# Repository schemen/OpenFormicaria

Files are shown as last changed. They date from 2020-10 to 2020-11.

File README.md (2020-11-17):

# OpenFormicaria

A Open Source modular ant formicarium and home with simple space saving connectors.

**Documentation:** [https://of.schemen.me](https://of.schemen.me)

**How to Contribute:** [https://of.schemen.me/contrib/](https://of.schemen.me/contrib/)

## Features overview

OpenFormicaria is a set of parts that interconnect expand upon another. Any part is compatible with any other part ranging from the small Portal where you can found your colony after the test tube up to interconnecting many formicaria.

All modules are based on a 35mmx35mm base grid for ability to interconnect all of them (At least connector facing parts). 4xGateway is 35x35mm, 6xGateway is 35x70mm. All of the modules are 20mm high.

* A variety of connectors to connect modules, formicaria, tubes etc.
* Connectors can be exchanged safely while the part is in use to prevent ant escapees.
* Different sizes of formicaria for different colony sizes
* Different formicaria insert styles for different ant species
* Easy way to create your own custom insert!
* Portal module with feeding access for a first small outworld to explore and expand
* 4x or 6x Gateway modules to expand the farm

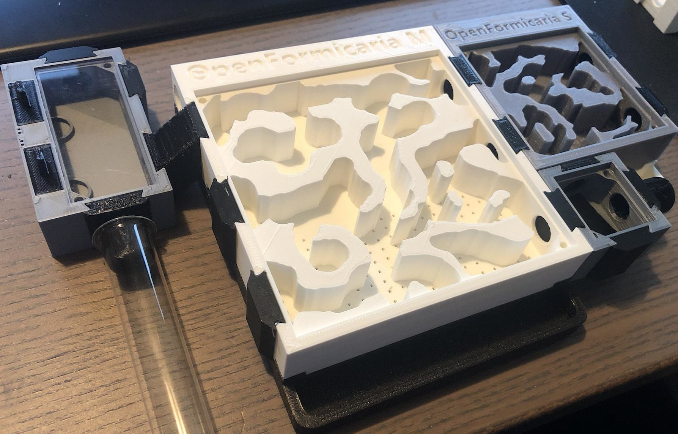
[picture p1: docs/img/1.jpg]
Example Farm


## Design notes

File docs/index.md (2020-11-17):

# Welcome to OpenFormicaria

This is a open source modular ant formicarium and home with simple space saving connectors.

## Features overview

OpenFormicaria is a set of parts that interconnect and expand upon another. Any part is compatible with any other part ranging from the small Portal where you can establish your colony after the test tube up to interconnecting many formicaria.

All modules are based on a 35mmx35mm base grid for ability to interconnect all of them (at least connector facing parts). 4xGateway is 35x35mm, 6xGateway is 35x70mm. All of the modules are 20mm high.

* A variety of connectors to connect modules, formicaria, tubes etc
* Connectors can be exchanged safely while the part is in use to prevent ant escapees
* Different sizes of formicaria for different colony sizes
* Different formicaria insert styles for different ant species
* Easy way to create your own custom insert!
* Portal module with feeding access for a first, small outworld to explore and expand
* 4x or 6x Gateway modules to expand the farm

Example Farm

## Reading On

Do you want to go ahead and print your own ant nest or a starting base?
Continue reading with [Getting Started](getting_started.md).

If you want to contribute, add more parts and modules, want to improve existing ones or simply want to help out, please have a look at [How to contribute](contrib.md)

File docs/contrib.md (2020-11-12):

# How to expand OpenFormicaria
There are several processes and standards within this project, so let's have a look at them.

Generally, I **recommend** using a existing CAD instance as reference and work with CV2 connector style.

You can find the repository here: [Github](https://github.com/schemen/OpenFormicaria)

Fork it and add your changes. 

## How to PR/MR on Github
When you have a creation you want to have added, make sure it is in the correct folder (STL exports, CAD files etc.).
Add the documentation of your part in to `docs` folder as well.

Please create PRs into the **devel** branch!

## Base structural blocks for any modules
A base block has the size of **35mmx35mmx20mm**. The 4xGateway has essentially those measurments. This square is essentially the base block size for connenctor facing faces.

You can see this with the the 6xGateway. On a side, they have two connector placements, this side has to be 70mm wide to fit both of them. A face that does not intend to have connectors, you are free to move out of this size. The example here would be the Portal. The face with the feeder holes is a bit outside of this box.

### Some other specs to modules
* The glass cut out is 3mm deep
* The m3 screw holes have a radius of 1.4mm
* The ant "cutout" is recommended to be around 15mm deep. This leads to have a 2mm floor with 20mm total height. 
* To hold the glass I've used a 1mm wide ledge sofar

## Connector
Please have a look at the folder `Measurements` with all the detailing measurements on how the connector looks like. 

A connector is set up with the following parts:

* Female Connector is on all Modules. Be aware in the difference of CV1 and CV2. Have a look at the image `Connector Cut Measurements`.
  * The hole cut through has a radius of **5mm** and is centered.
  * CV2 Female has a Hill that is in the center. Check `ConnectorV2_Hill` for it's specs
* Male connectors are standalone and are used in between to connect all modules. The CV2 version as a grove and a rail so that the Hill can slide and lock. 
  * Check out the images `ConnectorV2_Rail` and "`ConnectorV2_Groove` for the specs

## Formicaria
The formicaria are created in two steps:

**1)** A template is created and maintained for each size. This template is empty and does not have any ant digging site, just free space. This gets exported as STL.

**2)** In Photoshop or any editor of your preference a black/white plan of the ant pathways is drawn. This then get imported in 3D Builder and placed into the template, combining the two.

This approach allows to create many different inserts for the formicaria for different ant species. You can of course further customize the templates if you wish.

Have a look at `Formicaria/Inserts/` to find PSD templates and already generated ant styles.

## Helping in other ways

If you like the design and all the work that already went in, you could consider sponsoring a tea/coffe at [Buymeacoffee](https://www.buymeacoffee.com/schemen) as a motivator!

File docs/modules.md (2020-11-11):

# OpenFormicaria - Modules

## Available modules
A list of Modules that are available!
Note all modules are available in CV1(Legacy) and CV2 trim.

## Print recommendations
All modules can be printed with:

* 0.2mm layer height
* 15% infill
* PLA or any other hard material
* The feeder lids should be printed in TPU to press in properly.

Use a color that is relatively contrastring to your ants so you can see them.

## Portal
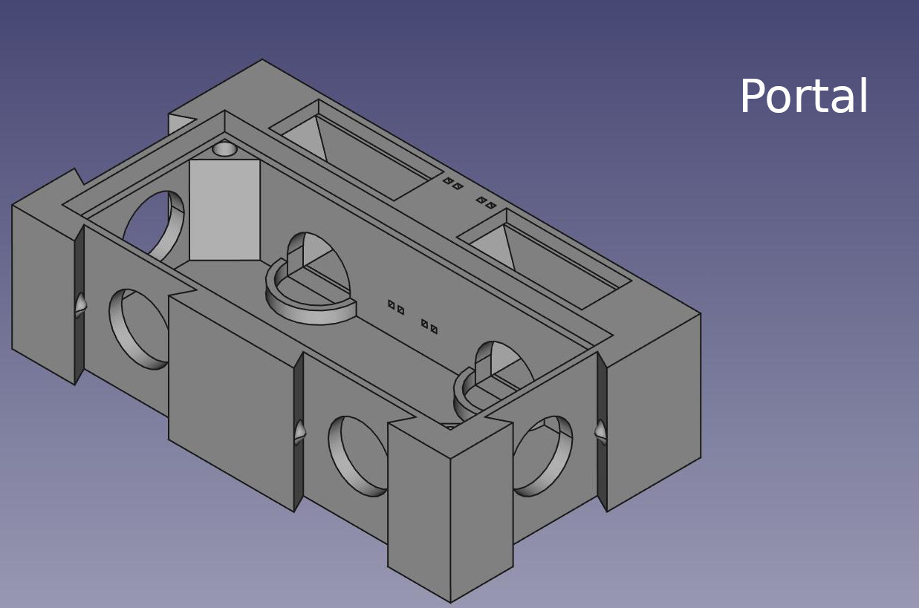
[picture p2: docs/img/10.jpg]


A module used for founding colonies. Connect your test tube with the queen and brood and the initial few workers here.
This module serves as the first small outworld!

Don't forget to print the cover and feeder lids. The feeder lids should be printed in TPU to press in properly.

### Features
* Size of 70mm x 40mm x 20mm
* Attach up to 4 other attachments
* Two feeding holes
* Air vents
* Lid to cover the ants if needed
* Either press fit or screw in plexiglass

### Plexiglass sizing
The glass cutout is 26mm x 62mm. If you want, you can use a small drill bit that fits M3 screws.

## 4xGateway
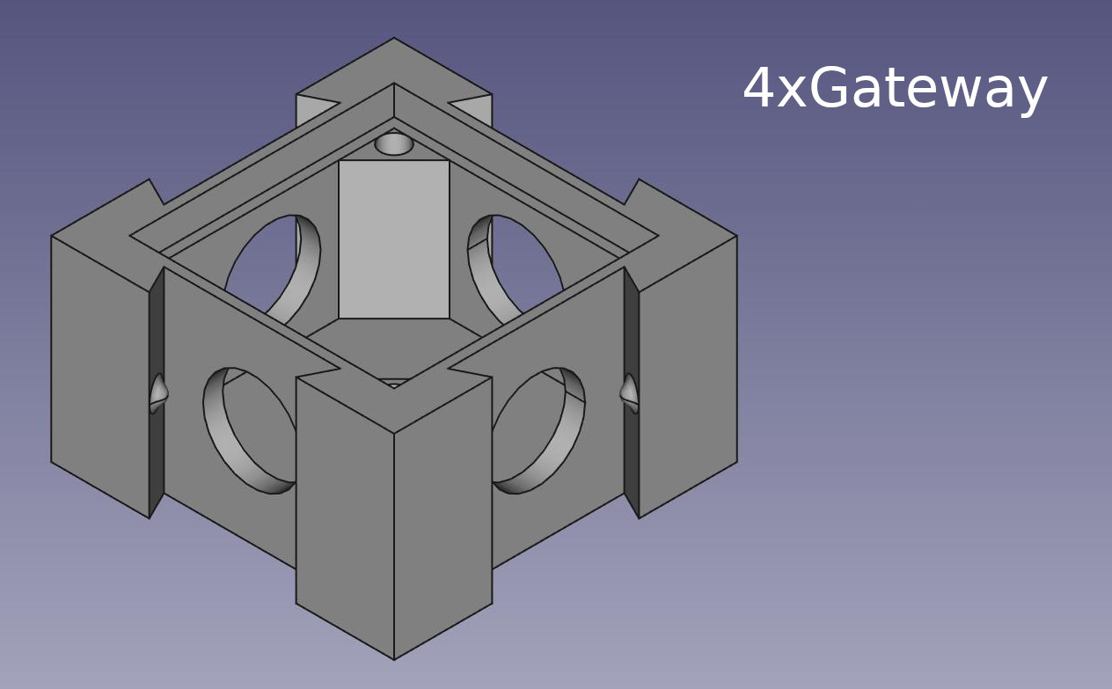
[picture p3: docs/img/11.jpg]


### Features
* Size of 35mm x 35mm x 20mm
* Attach up to 4 other attachements
* Plexiglass for your viewing pleasure

### Plexiglass sizing
The glass cutout is 27mm x 27mm. If you want, you can use a small drill bit that fits M3 screws.

## 6xGateway
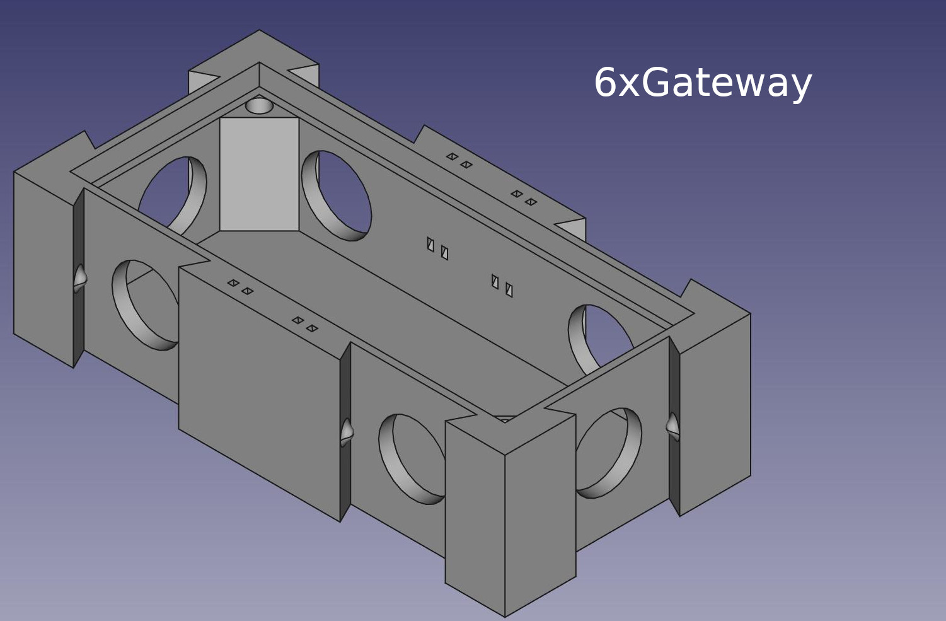
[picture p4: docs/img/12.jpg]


### Features
* Size of 70mm x 35mm x 20mm
* Attach up to 6 other attachements or things that can have two or more at the same time!
* More space
* Air Vents
* Plexiglass for your viewing pleasure

### Plexiglass sizing
The glass cutout is 62mm x 27mm. If you want, you can use a small drill bit that fits M3 screws.

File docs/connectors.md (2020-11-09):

# OpenFormicaria - Connectors

The images will be for CV2 mostly, though in most cases the information is valid for both version, if not explicitly said so.

## Print recommendation
### CV2 (recommended)
You have to use TPU or a similar flexible material.

* 0.2mm layer height is fine
* 15% infill
* Tube connectors require support, everything else can be printed without

### CV1
PLA is fine for most connectors, though the tube connector will not work properly with PLA.

* 0.2mm layer height is fine
* 15% infill
* Tube connectors require support as well as has to be printed with TPU, everything else can be printed without supports

## Main Connector 
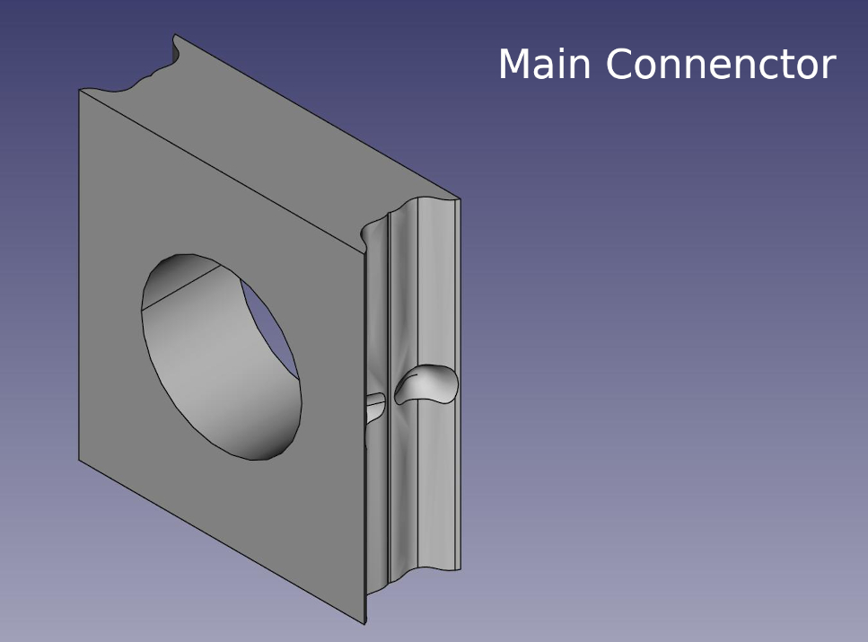
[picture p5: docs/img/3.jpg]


This connector connects two modules together, simple enough.

## Connector blocker
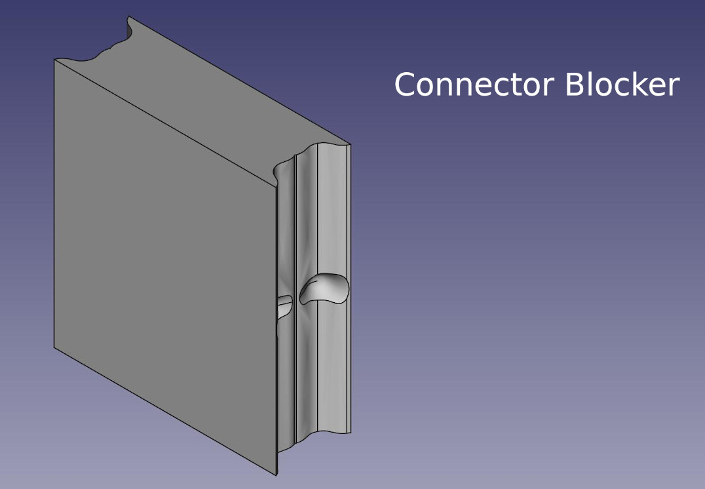
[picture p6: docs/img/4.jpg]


Same formfactor as the Main connector but it blocks the path.

## Tube Connectors for 10mm, 12mm and 14mm inner circumference
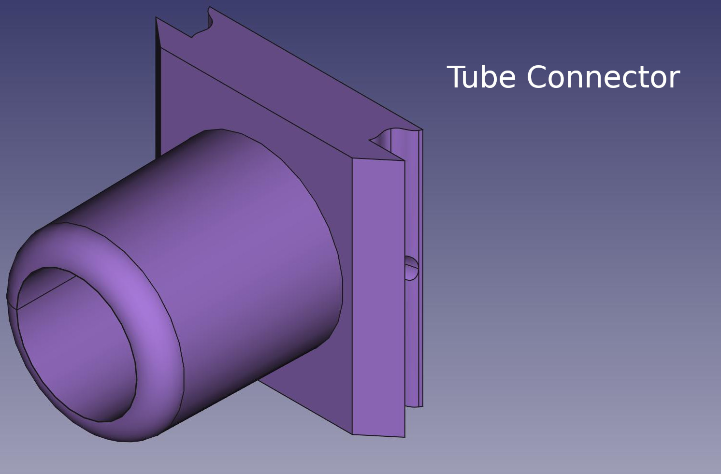
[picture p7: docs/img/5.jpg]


A variation of tube connectors. The test-/tubes go over the connector, not in.

**IMPORTANT**! Do not print this with PLA, use a flexible filament.

## Tube Connectors on an 90° angle for 10mm, 12mm and 14mm inner circumference
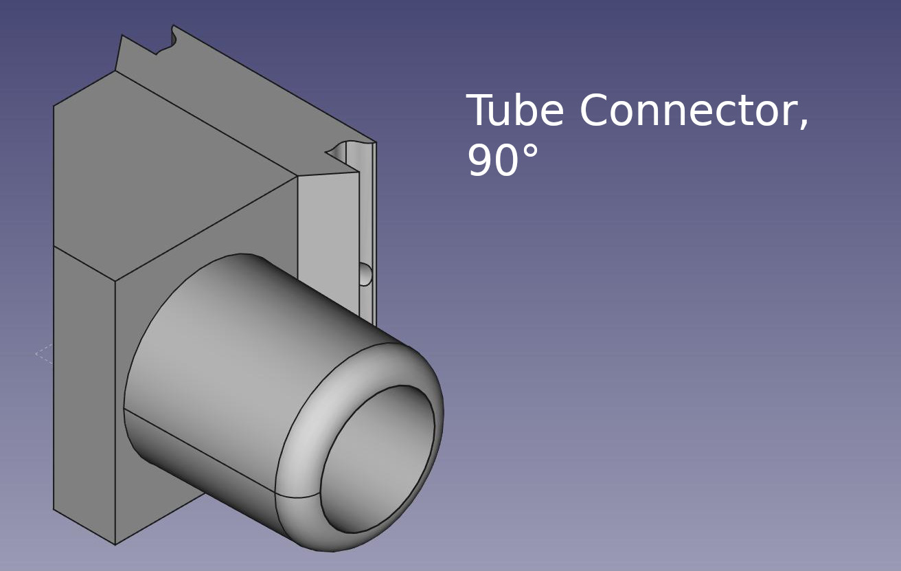
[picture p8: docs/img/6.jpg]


A variation of tube connectors. The test-/tubes go over the connector, not in.

IMPORTANT! Do not print this with PLA, use a flexible filament.

## Blocking Endpoint
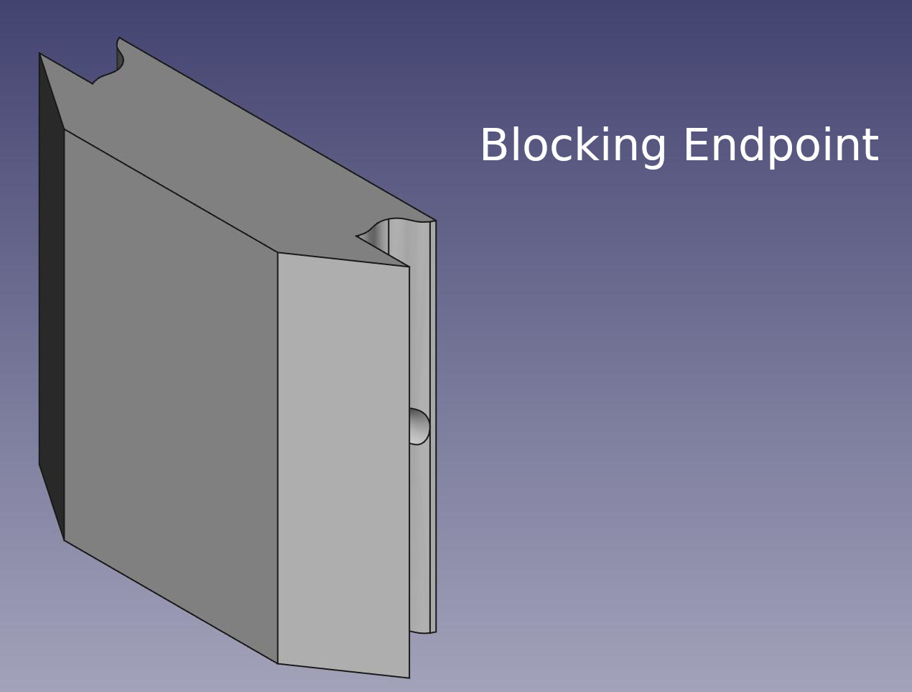
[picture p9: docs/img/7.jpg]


A bit nicer looking than a block connector but cannot be used to connect two modules

## Connector Raiser 
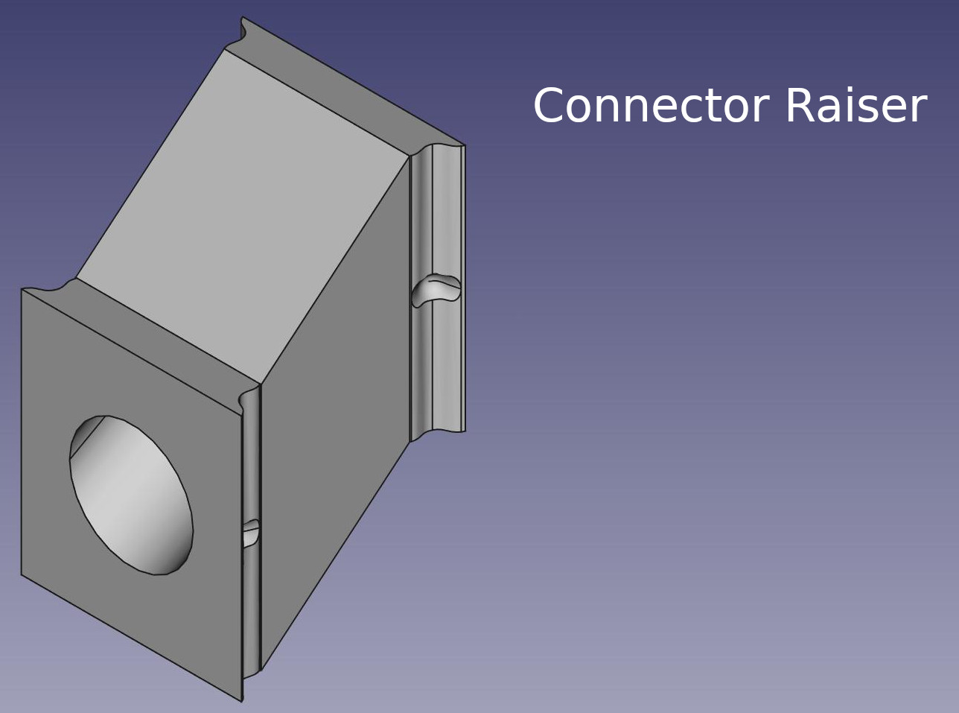
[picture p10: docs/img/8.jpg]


This connector allows you to connect a modules like a Portal to a formicarium which is higher above due to the basin. Now there is no more floating modules.

## Separator (CV2 only)
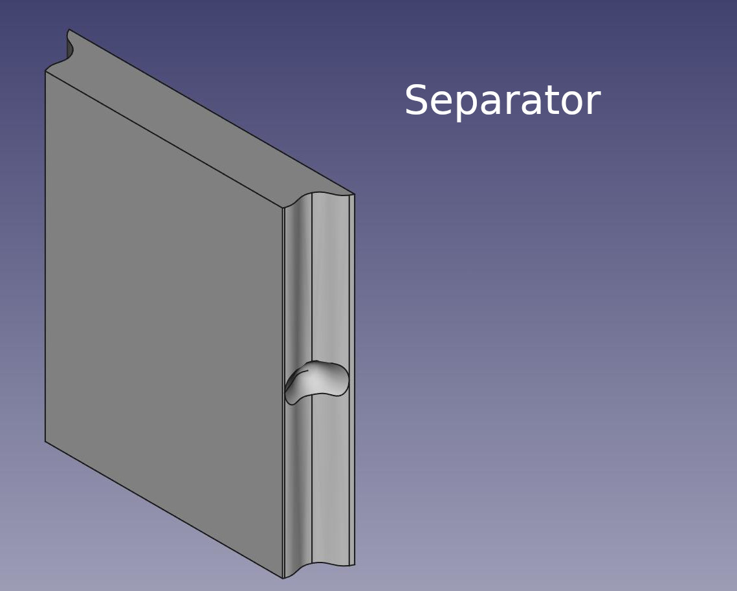
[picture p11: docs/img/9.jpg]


This "connector" allows you to separate two connected modules and block both entries. I recommend to print at least a pair of these for your setup.

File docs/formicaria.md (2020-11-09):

# OpenFormicaria - Formicaria

## General Features
* Modular - any type of insert can be made for specific ant requirements and preferences
* Water Basin Stack for hydration and humidity regulation
* Heat Cable insert
* Cover to give the ants a dark environment
* Plexiglass can be press fitted or via screws
* All Formicaria are available in CV1(Legacy) and CV2 trim

Don't forget to print the basin and lid for your nest!

## Formicaria Size S
Small size formicarium, 70mm x 80mm x 20mm.

### Template Size S
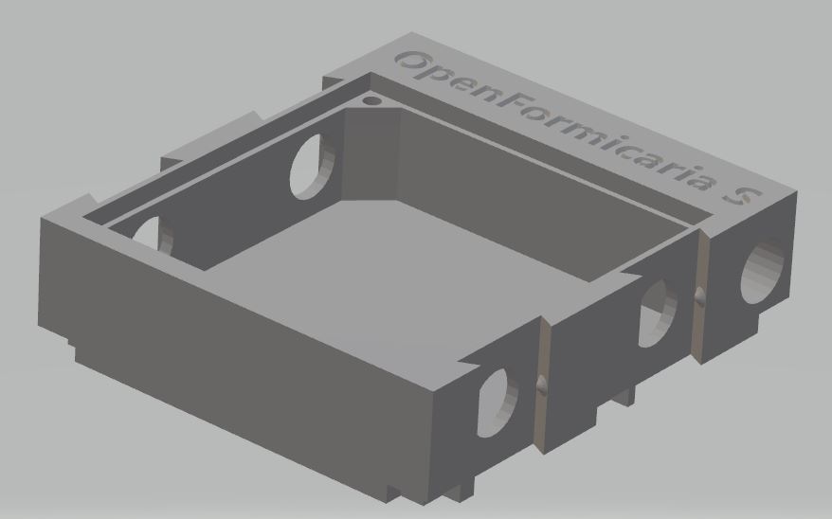
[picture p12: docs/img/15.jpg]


Do it yourself with Photoshop and Microsoft 3D Builder!

### Lasius S
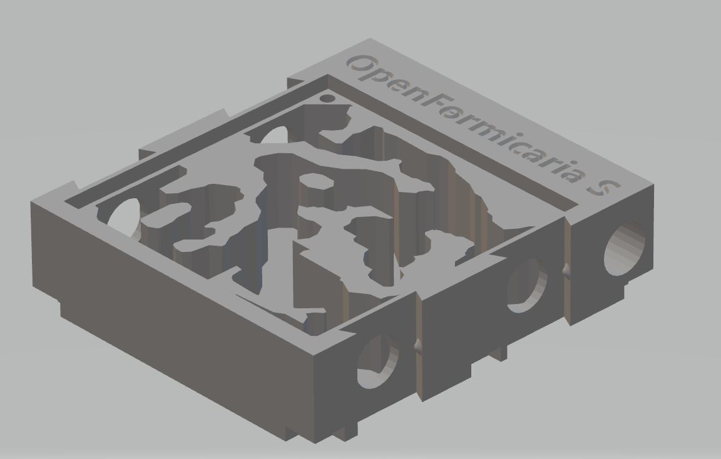
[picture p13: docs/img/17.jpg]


Lasius nest inspired insert

### Plexiglass sizing
The glass cutout is 62mm x 62mm. If you want, you can use a small drill bit that fits M3 screws.

## Formicaria Size M

Medium size formicarium, 105mm x 115mm x 20mm.

### Template Size M
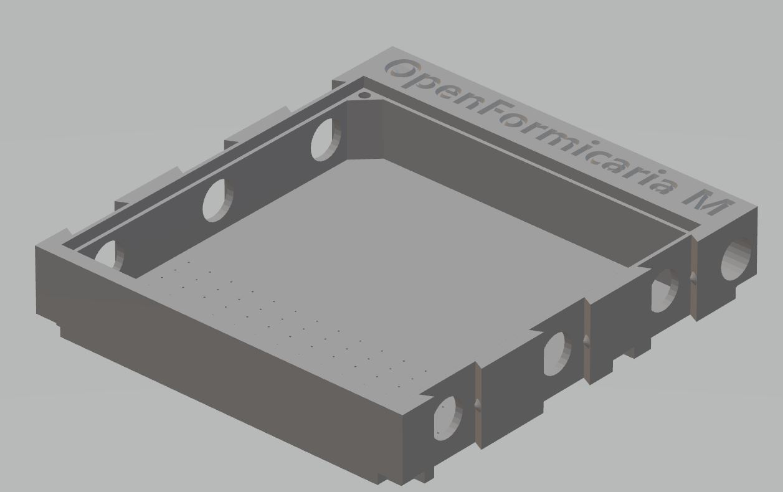
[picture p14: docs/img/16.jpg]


Do it yourself with Photoshop and Microsoft 3D Builder!

### Lasius M
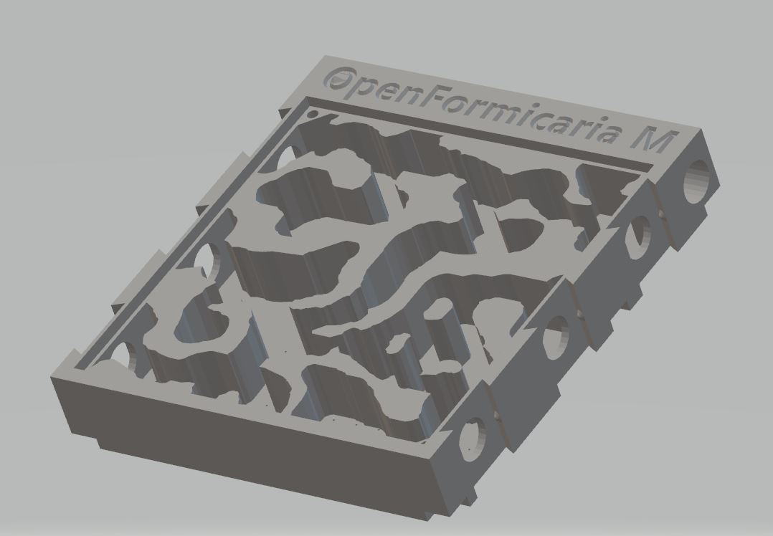
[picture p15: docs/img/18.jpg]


Lasius nest inspired insert

### Plexiglass sizing
The glass cutout is 97mm x 97mm. If you want, you can use a small drill bit that fits M3 screws.

## Other sizes
* Coming soon!

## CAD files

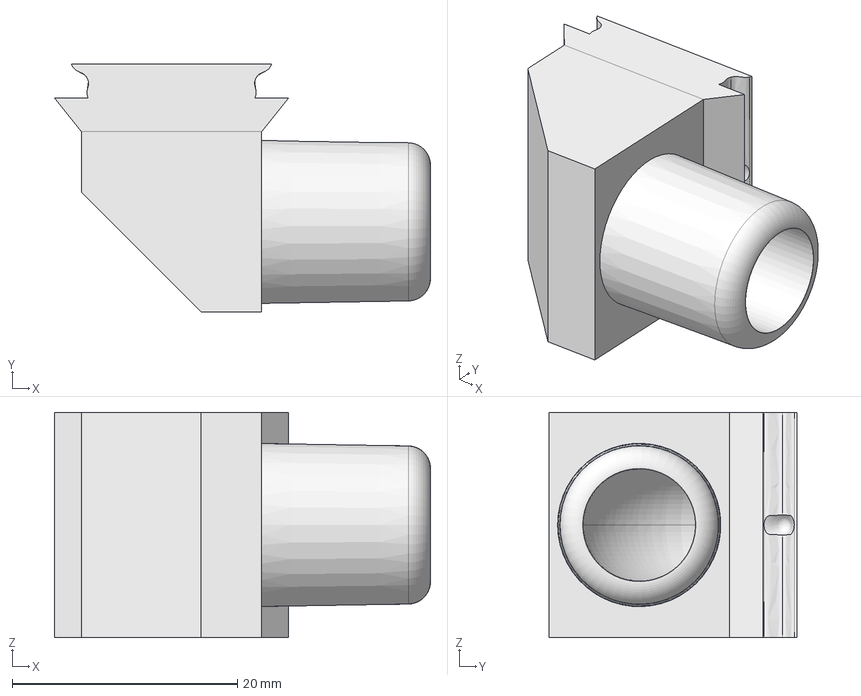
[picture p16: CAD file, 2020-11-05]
Connectors/CAD/Connector Version 2/V2_Connector_90deg_tube_14mm.FCStd
33.4 x 22.0 x 20.0 mm

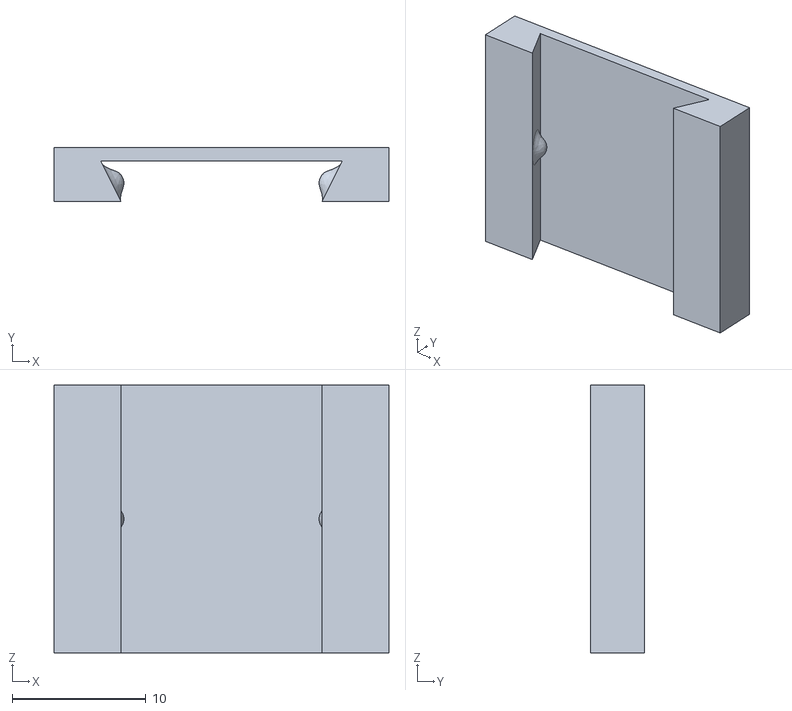
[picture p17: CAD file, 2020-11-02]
Connectors/STL/connectorv2.stl
25.0 x 4.00 x 20.0

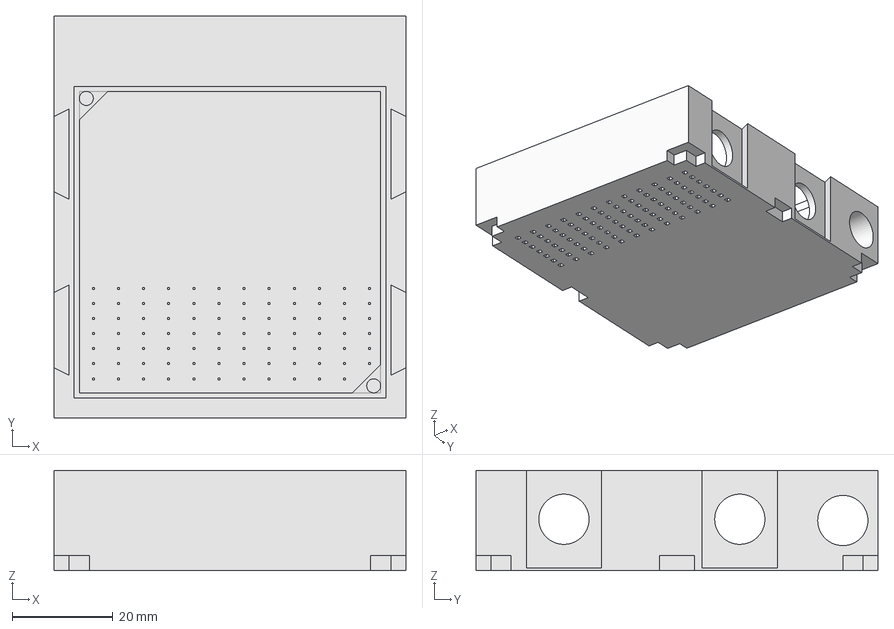
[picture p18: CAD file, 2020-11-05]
Formicaria/CAD/CV1/Formicarium_Template_S.FCStd
70.0 x 80.0 x 20.0 mm

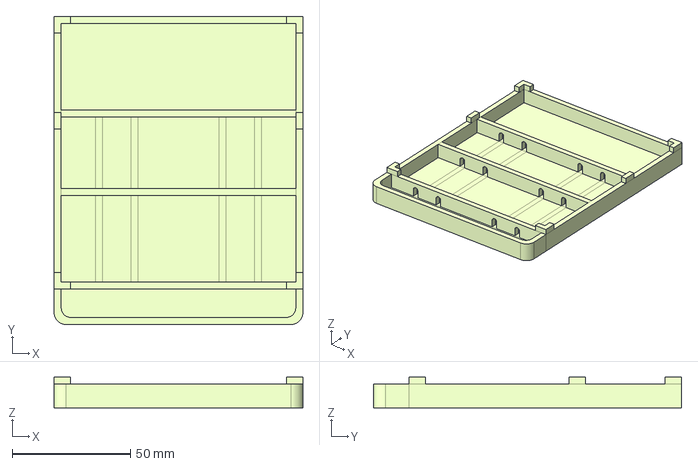
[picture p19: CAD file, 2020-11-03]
Formicaria/CAD/Formicarium_basin_M.FCStd
105.0 x 130.0 x 13.0 mm

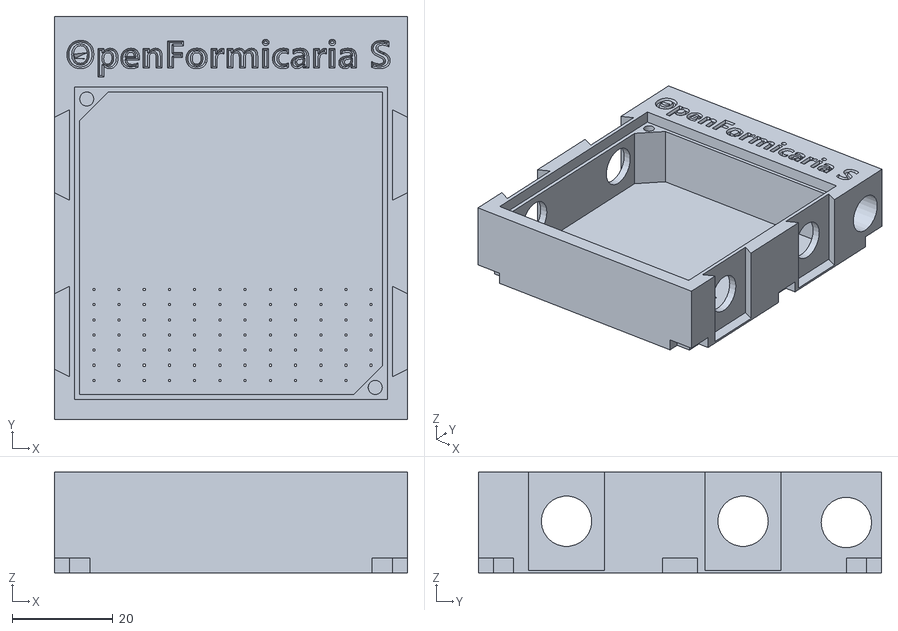
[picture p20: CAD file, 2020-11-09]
Formicaria/STL/CV1/OF_Formicarium_Template_S.stl
70.0 x 80.0 x 20.0

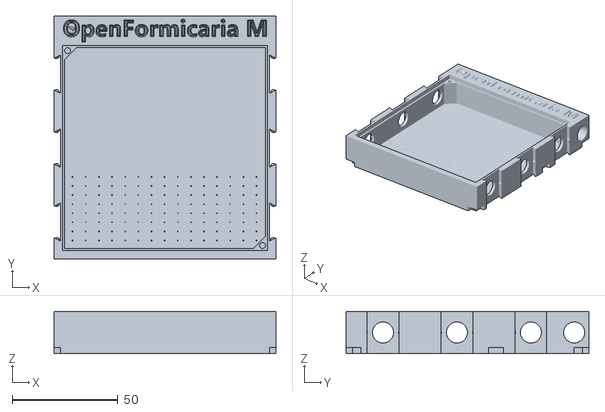
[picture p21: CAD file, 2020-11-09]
Formicaria/STL/CV2/CV2_OF_Formicarium_Template_M.stl
105.0 x 115.0 x 20.0

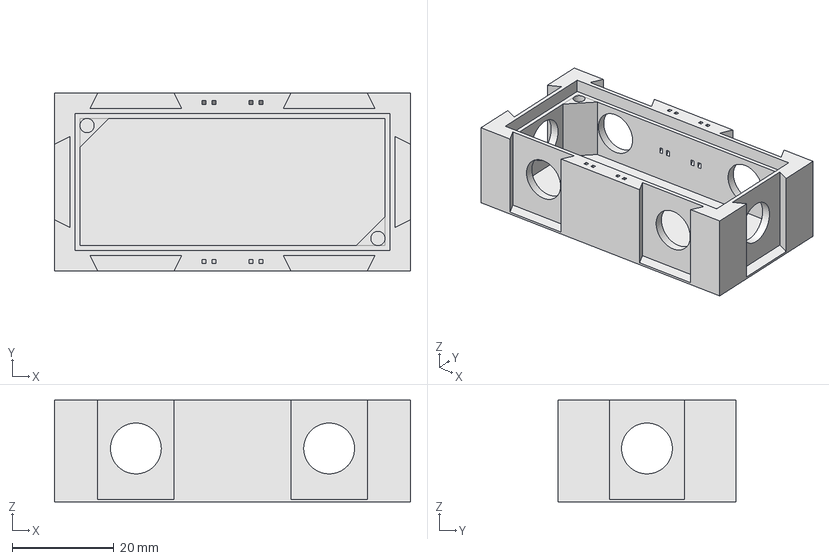
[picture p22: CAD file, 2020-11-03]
Modules/CAD/CV1/6xGateway.FCStd
70.0 x 35.0 x 20.0 mm

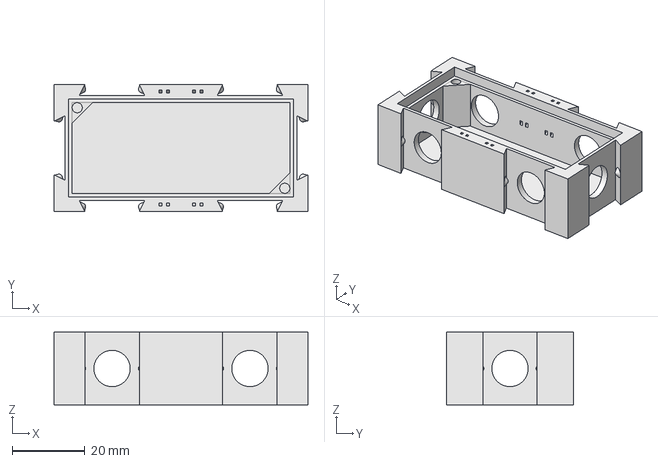
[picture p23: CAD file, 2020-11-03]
Modules/CAD/CV2/CV2_6xGateway.FCStd
70.0 x 35.0 x 20.0 mm

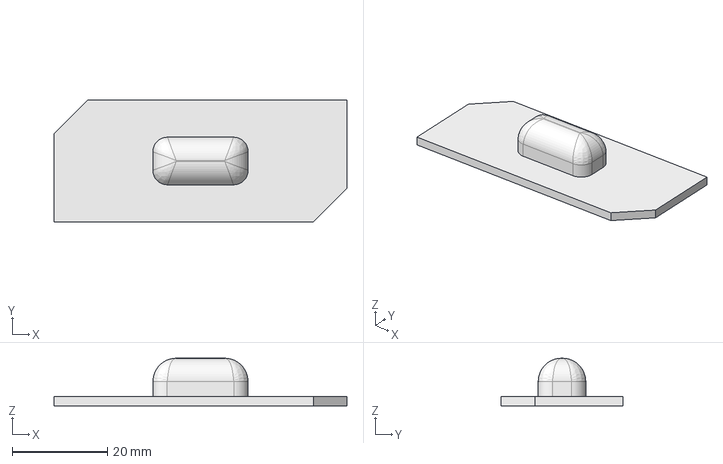
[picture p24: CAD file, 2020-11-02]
Modules/CAD/Portal_Lid.FCStd
61.6 x 25.6 x 10.0 mm

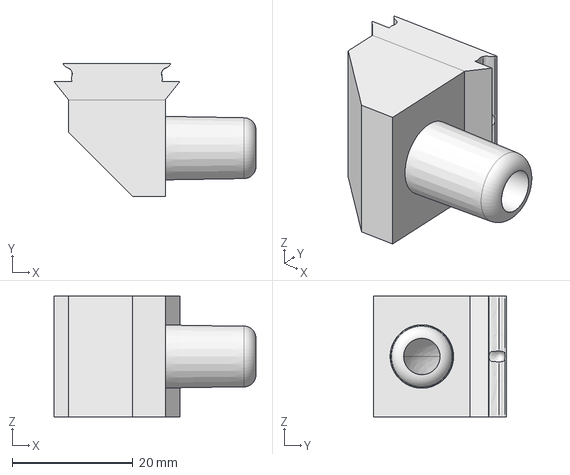
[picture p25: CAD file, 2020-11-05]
Connectors/CAD/Connector Version 2/V2_Connector_90deg_tube_10mm.FCStd
33.4 x 22.0 x 20.0 mm

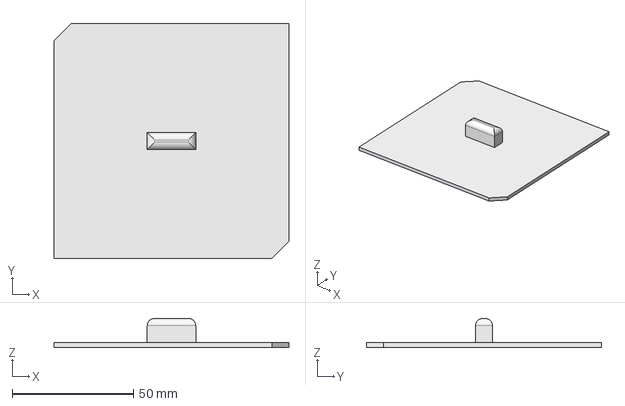
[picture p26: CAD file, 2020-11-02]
Formicaria/CAD/Formicarium_Lid_M.FCStd
96.9 x 96.9 x 12.0 mm

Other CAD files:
Formicaria/CAD/CV2/CV2_Formicarium_Template_S.FCStd
Formicaria/STL/OF_Formicarium_Basin_M.stl
Modules/STL/CV1/OF_6xGateway.stl
Modules/STL/OF_Portal_Lid.stl
Formicaria/CAD/CV1/Formicarium_Template_M.FCStd
Formicaria/CAD/CV2/CV2_Formicarium_Template_M.FCStd
Formicaria/STL/CV1/OF_Formicarium_Template_M.stl
Connectors/CAD/Connector Version 1/Blocker_Endpoint.FCStd
Connectors/CAD/Connector Version 1/Connector.FCStd
Connectors/CAD/Connector Version 1/Connector_block.FCStd
Connectors/CAD/Connector Version 1/Connector_high_tolerance.FCStd
Connectors/CAD/Connector Version 1/Connector_raiser.FCStd
Connectors/CAD/Connector Version 1/Connector_tube10mm.FCStd
Connectors/CAD/Connector Version 1/Connector_tube12mm.FCStd
Connectors/CAD/Connector Version 1/Connector_tube14mm.FCStd
Connectors/CAD/Connector Version 2/V2_Blocker_Endpoint.FCStd
Connectors/CAD/Connector Version 2/V2_Connector.FCStd
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

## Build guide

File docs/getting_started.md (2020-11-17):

# Getting Started

## Download
You can download all the parts on [Thingiverse](https://www.thingiverse.com/thing:4637707) or directly on the repository on [Github](https://github.com/schemen/OpenFormicaria) for the latest files. You can find the files in the corresponding `STL` folders

## Required Materials
You will need any hard filament (PLA, PETG) for CV1. If you want to use CV2 (which is recommended) you will need a flexible filament like TPU or Flex.

## Connector Version 2 (CV2) and Connector Version 1 (CV1)
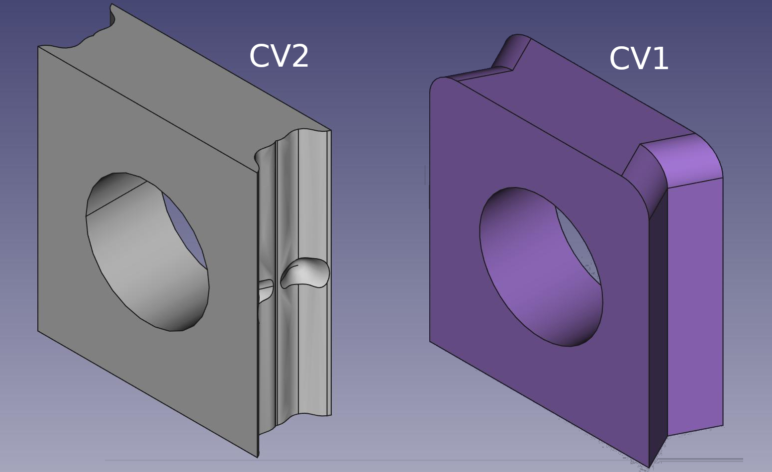
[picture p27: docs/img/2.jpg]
CV2


There are two version available, both are similar in design with version 2 being improved. The only reason not to use CV2 is if you do not have any flexible filament, CV1 will work for you in that case.

With CV2 you can seemlessly switch connectors that are in use, for example allowing you to block passages between modules by switching out a Connector with a Blocker.

Note that all CV2 connectors **have** to be printed in TPU or any flexible material.

## Part list
You can check out the parts available:

* [Connectors](connectors.md)
* [Modules](modules.md)
* [Formicaria](formicaria.md)

## Set suggestions and Ideas

### The Base Kit - A initial home
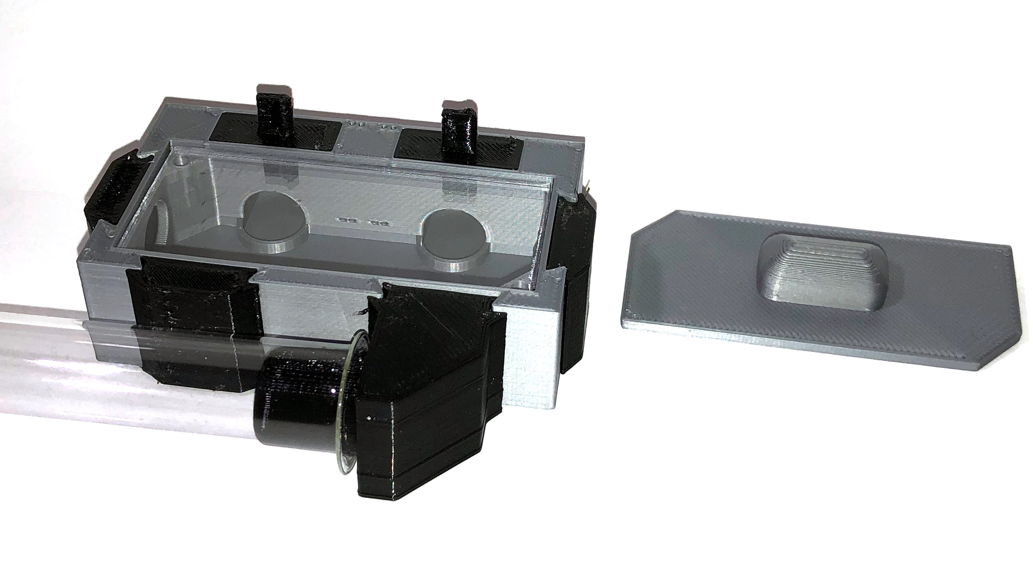
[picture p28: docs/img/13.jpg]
Basekit


If you have a test tube setup and you think your ants are ready for their first scavenging outside of it, while still to small for a proper outworld, you can use a Portal! This allows you to connect several other modules and connectors to it.

Here is a list of the items you should print for a base kit with a Portal. Once you have that, you can expand as needed!
Note that I do recommend printing all CV2 if you have a flexible filament available.

#### The Base Kit
* 1x Portal
  * 2x Portal Feeder Lids
  * 1x Portal Lid
  * 26mm x 62mm x 2mm Plexigass
* 2x Separators (CV2 Only)
* 3x Endpoint Blocker
* 2x Tube connector fitting your test tube size
  * The second tube connector can be used to add water or lead to a proper outworld

### A first Formicarium - Expanding your colony
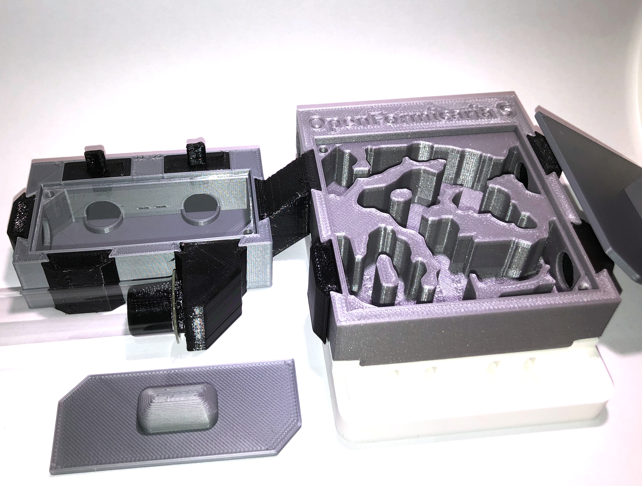
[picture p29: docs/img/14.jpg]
Fromicarium


Once the colony has outgrown the test tube setup and needs a proper nest you can start with a S sized nest that fits your colony! 
You can connect your Formicarium directly to the portal or use tubing to connect to it.

Generally, I recommend printing the base kit anyway and expand from there.

#### Your first Formicarium
* 1x S Sized formicarium for your ants
  * 62mm x 62mm x 2mm Plexiglass
* 3x Endpoint Blocker (4x if you want to connect via tubes)
* 1x Connector Raiser(direct connect)
* 1x Tube connector (tube connection)

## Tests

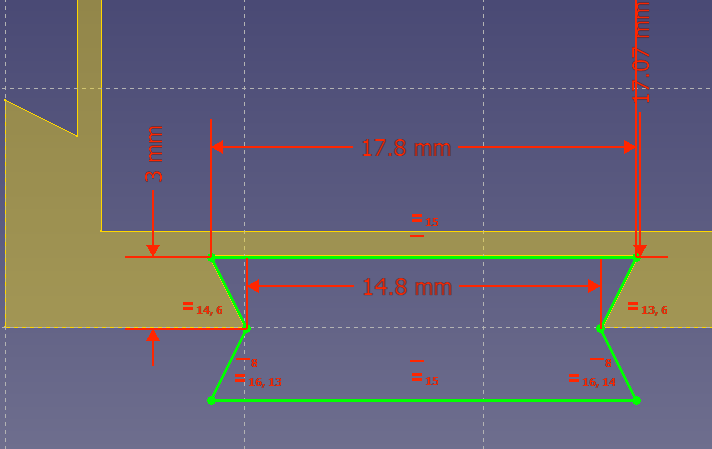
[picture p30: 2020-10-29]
Measurements/Connector Measurements_low_tolerance.png

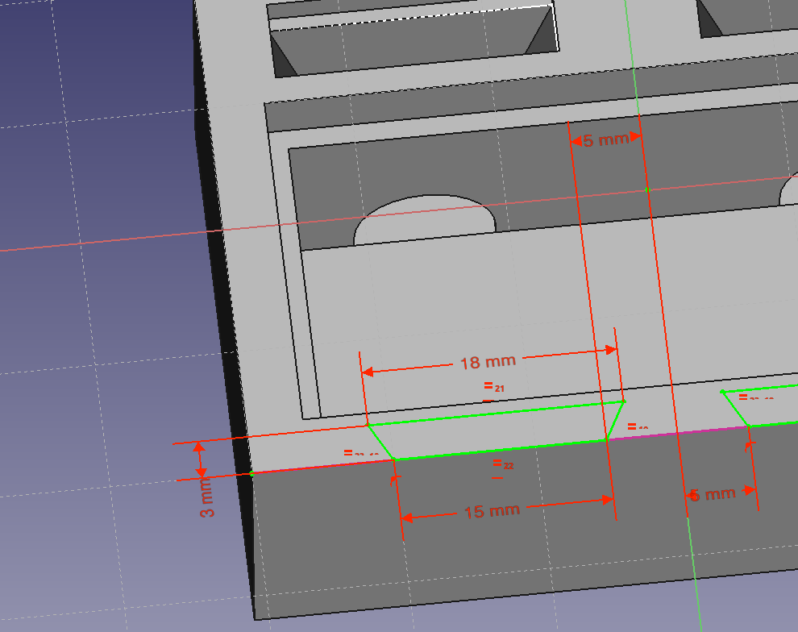
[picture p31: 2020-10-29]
Measurements/Connector Cut Measurements.png

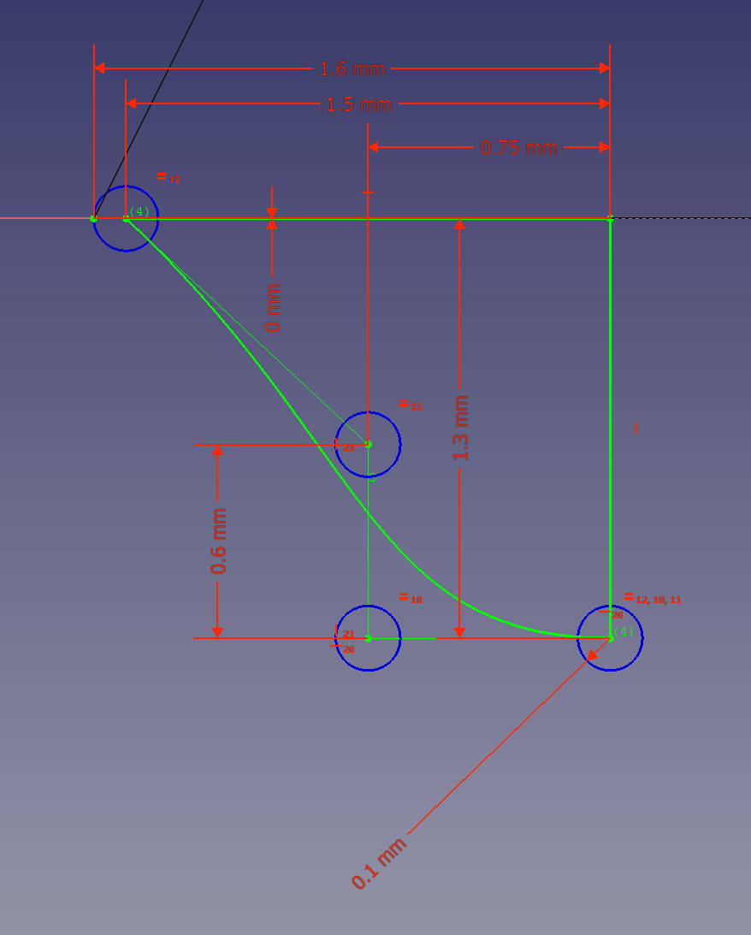
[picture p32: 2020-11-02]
Measurements/ConnectorV2_Groove.PNG

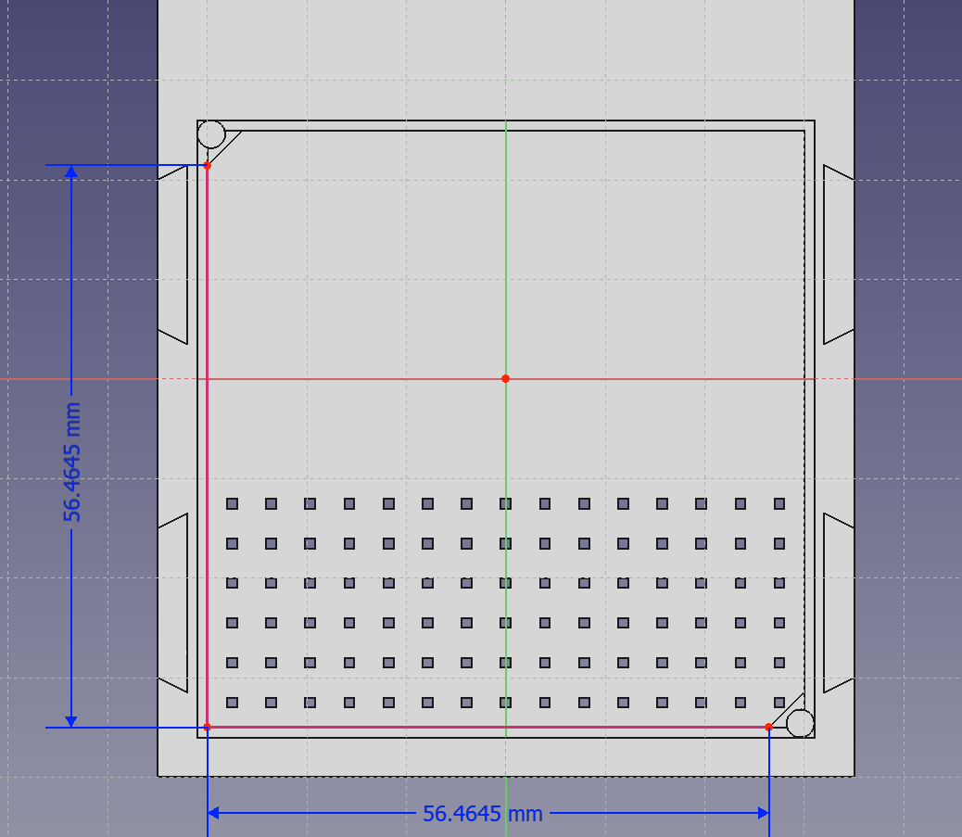
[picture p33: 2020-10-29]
Measurements/Fromicarium Insert size.PNG

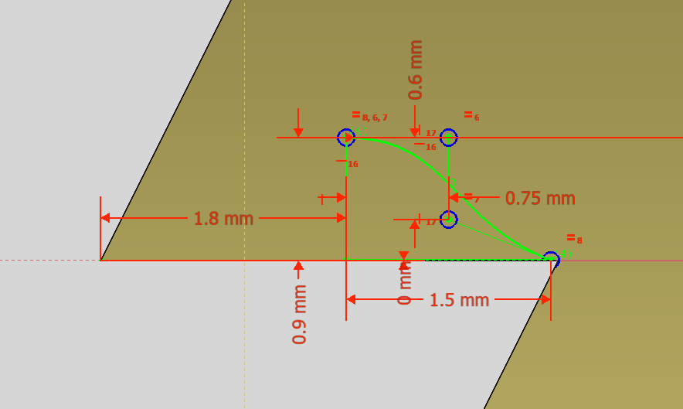
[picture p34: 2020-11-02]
Measurements/ConnectorV2_Hill.PNG

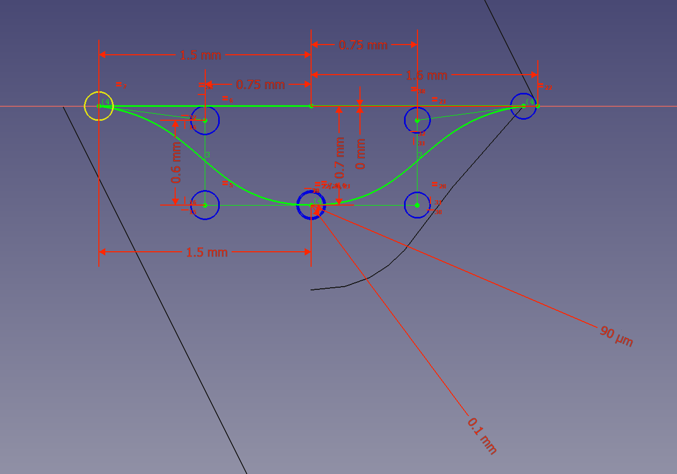
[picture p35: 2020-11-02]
Measurements/ConnectorV2_Rail.PNG

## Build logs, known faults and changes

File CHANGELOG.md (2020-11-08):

# Updates/Changelog
**2020.11.08**
* Started documentation at https://of.schemen.me

**2020.11.05**
* Added Tube connectors with a 90° angle. Only available for CV2 for now.

**2020.11.05**
* Changed formicaria humidity holes into funnel shaped holes to improve printing
  * Because the hole is in shape of a funnel it can be a lot tighter on the top level. The holes facing the ants are now 0.4mmx0.4mm big!

**2020.11.02**
* Added 6xGateway
  * More space or broader attachement to other modules!

**2020.11.01**
* Small fixes
* Added Connector raiser for CV1 and CV2. With that, you can connect modules like the Portal to a formicarium without it floating! 
* Added Separators, only CV2. This allows you separate connected modules while blocking both ends!

**2020.11.01**
* Fixed m3 boreholes
* Updated the Portal Lid to accomodate the borehole
* Introduce the Connector Version 2!
  * Improved design, now also able to prevent escapee ants when changing connectors or modules!

**2020.10.30**
* Added Size M Formicarizm with a Lasius inspired filling! Download or check the Zip file

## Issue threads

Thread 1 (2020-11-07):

Can´t open V2_Connector_90deg_tube10mm.stl

M00Nbeam, 2020-11-07:
Hi, I can´t open V2_Connector_90deg_tube10mm.stl

schemen, 2020-11-07:
heyo!

I have fixed it with https://github.com/schemen/OpenFormicaria/commit/597b1aac63ff105e4bd7caaf252c8e0b19a316a0

Let me know if things work for you!

Closed 2020-11-09.

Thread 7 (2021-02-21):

Which tube connector for test tube?

BjornB2, 2021-02-21:
Hi!

Thanks for your design. I am currently printing a new home for my ants :)

In the documentation it says the test tube goes over the tube connector, but what are the outer diameters of the 3 tube connectors? Only the inner diameters are specified (although it's called circumference which is incorrect I think).

Thanks
Björn

schemen, 2021-02-21:
Hi!

I then think it's a wrong wording. The circumference is the outside of the tube connectors.

I think I should also change the wording there. It's meant to be the outer circumference of course! (Inner would not really help you at all :) )

BjornB2, 2021-02-21:
Ah that clears it up. But I also need to attach tubes from my old nest and those are 10mm outside diameter. Cant put them over a tube connector since the hole would be to small for the bigger ants i am afraid. I'll check the cad files tomorrow.

schemen, 2021-02-21:
Ah gotcha, whats the inside diameter? 8mm? That should be fairly easy to modify in CAD

BjornB2, 2021-02-24:
Inside diameter would be to small to put it over a tube connector. The final hole would be to small for the bigger ants. I have harvester ants and they have some really large ants.  It would be better to stick the hose in the connector so to make the hole in the connector 10mm.

schemen, 2021-02-24:
Gotcha, feel free to add a connector like that. Otherwise, if you give me the exact specs I can cook something up in the following days.

BjornB2, 2021-03-06:
I just found out that the 14mm tube connector has a 10mm hole, so I can use that one for my 10mm connection hose :)

Closed 2021-03-29.

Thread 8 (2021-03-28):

Hydration Holes Too Big

CosmisEntity992, 2021-03-28:
To start, you've created a really amazing nest and I appreciate all the work you've put into it.

I've tried this nest with L Niger and M Rubra, both SPs are small enough to fit through the hydration holes relating in a mass ant exodus lol. Is there any way these can be made smaller? If not, an alternative hydration method?

schemen, 2021-03-29:
Hey, thanks for the feedback, sorry to hear the experience!

Could you let me know what version you printed with what material and printer settings?
I myself have L Niger and they and they cannot escape, the holes are in a reverse funnel shape and the ant facing side is only 0.4mm wide, so only the smaller species should be able to escape but it would require a well calibrated printer.

Make sure you have good, dry filament (you can dry it before hand in a oven) and glue the hole side on the plate, it helps usually.

Let me know!

fharni, 2021-03-29:
I have the same problem. I have printed the M size nest for my niger in PLA. They can clip through the tiny holes. Now I have pushed a lot of wet cotton wool under the holes. Maybe filling these holes with plaster may help.

CosmisEntity992, 2021-03-29:
Yeah it only seems to be the smaller workers and only certain of the holes
as well. Lots of cotton is a good shout, I will give that a try.

On Mon, Mar 29, 2021 at 2:35 PM James Avis ***@***.***>
wrote:

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

--
James Avis

schemen, 2021-03-29:
@CosmisEntity992 @fharni
I found the problem. The Lasius S and M for the CV1 don't have the new funnel style holes, I forgot to update those models from the templates.

Generally I do recommend you use CV2 though :) I will create a MR to fix the template for Lasius S and M CV1, they indeed have the "old" hole system, sorry about that!

schemen, 2021-03-29:
https://github.com/schemen/OpenFormicaria/commit/d5552012e1697723fd217b831402167c913935b2 I have updated the two STL files, please have a look and let me know! With those, it should not be possible for those SP to escape :)

Sorry for the hassle, I didn't realize the CV1 formicaria had not been updated.

CosmisEntity992, 2021-03-29:
Dude don't be sorry, I just appreciate the work you've put into this. I
will get a print going now and will test! I haven't been printing CV2 as I
don't have any flexible filament for the connectors etc.

Thanks again :)

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

--
James Avis

schemen, 2021-03-31:
@CosmisEntity992 Do you have an update on the print? Did it manage to print successfully :) ?

CosmisEntity992, 2021-03-31:
Hey yes! I was meaning to email you. Printed successfully, some of the
holes are smaller than the others which I guess would be down to a setting
on my printer. Though, no ants are getting through those!

I will print the M nest as well :)

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

schemen, 2021-03-31:
The size was close to the limit my printer was able to handle as well, but they work :) Worst case you can take a very fine needle to help a little bit if it's entirely closed.

Any chance you could post a picture? maybe even a make on thingiverse?

Closed 2021-04-26.

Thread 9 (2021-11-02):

Location of M3 Screw Holes

GadgetUK, 2021-11-02:
Is there a drawing that gives the location of the M3 holes from the edge of the plexiglass ?

schemen, 2021-11-03:
Hm, I don't have a sketch I'm afraid!

You could hold the glass over the nest and drill the holes like that, since it's transparent.

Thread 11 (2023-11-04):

Is this project still active?

Nohus, 2023-11-04:
Looks super cool, but the website says "Coming soon!" for some things and there were no updates for over 2 years. :smile:

nakhleh, 2024-04-14:
I had the same question. Just built a starter setup...great instructions and models. I had some things I thought I could contribute... I made SVGs for laser-cutting the plexi formicarium lids, was thinking of re-designing the screw-holes to support brass inserts, and making new connectors for larger test tubes. Would be happy to contribute back, if maintainer is still tracking the project.

schemen, 2024-04-28:
I'm active here, but less so on this project. I keep the repo open though, anyone is welcome to contribute.

I've freed my colonies as well, so I don't have any active colony to test things anymore!

cristiangrojas, 2024-05-01:
Weird! This is a pretty cool project, I'll start printing mine and hopefully at some point will be able to contribute as well

nakhleh, 2024-05-01:
Excellent, @schemen! I've already got some local additions (new connector sizes, SVGs for laser-cutting acrylic lids, etc.) but am currently working on making an outworld that's compatible with the system. I'll submit some PRs once I have everything up and tested.
Thanks again for putting this nice setup out there in open source, and providing FreeCAD models of everything. It's been very helpful, even though I'm still a novice with FreeCAD.

nogarth, 2025-04-01:
@nakhleh did you make your additions and if so where did you post them.

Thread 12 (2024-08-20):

V2 connectors with TPU

MysticalMount, 2024-08-20:
Hi, Ive printed my portal and its my first time using TPU, the shape looks ok, but when inserting say the V2_Connector_Blocker I can see there is a small gap there when inserted because the flexible plastic is slightly squeezed.

My past experience with ants, especially Lasius Niger is they are little escapees.  How concerned shoudl I be about that tiny gap - and is there any print settings that might make the gap go away?

Appreciate if the project isnt active, of all the formicariums out there this one is the nicest so Ive chosen it!  Wondering if pla for the blockers i a tighter fit and use V1, but stick with V2 for the tube connector.  Will I have same problem then though?

schemen, 2024-08-21:
So, TPU is a fickle material. My suggestion here would be to play a bit with the scale.

It is usually enough to increase the size 1-2%, maybe more. I can't fully norm it since every printer and every TPU material prints a bit differently but I'd suggest to scale it up a bit if you see a bit of a gap.

The idea of using TPU is that it's flexible, allowing you to squeeze it in.

MysticalMount, 2024-09-01:
Mucxh thanks will give that a go and report back

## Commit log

2020-10-29 First push
    [4xGateway.FCStd, Blocker_Endpoint.FCStd, Combined.FCStd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]
2020-10-29 Structure update
    [4xGateway.FCStd, Blocker_Endpoint.FCStd, Combined.FCStd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]
2020-10-29 restructuring and READMEs
    [Formicarium_Lid_S.FCStd, Formicarium_Template_S.FCStd, Formicarium_basin_S.FCStd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]
2020-11-02 All the new things!
    [4xGateway.FCStd, Blocker_Endpoint.FCStd, CV2_4xGateway.FCStd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]
2020-11-03 Add 6xgateway + multiple updates
    [6xGateway.FCStd, CV2_6xGateway.FCStd, CV2_6xGateway.stl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]
2020-11-05 Implemented the new Siphon hole style
    [CV2_Formicarium_Template_M.FCStd, CV2_Formicarium_Template_S.FCStd, CV2_OF_Formicarium_Template_M.stl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]
2020-11-05 Update readme and new lasius formicarium
    [CV2_OF_Formicarium_Lasius_S.stl]
2020-11-05 Add right angle test tube connector
    [V2_Connector_90deg_tube10mm.stl, V2_Connector_90deg_tube12mm.stl, V2_Connector_90deg_tube14mm.stl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]
2020-11-07 Fix conenctor STL export
    [V2_Connector_90deg_tube10mm.stl]
2020-11-08 Add marks to template formicaria, doc typos
    [CV2_OF_Formicarium_Template_M.stl, CV2_OF_Formicarium_Template_S.stl, OF_Formicarium_Template_S.stl]
2021-03-29 Fix CV1 firmicaria to use funnel style holes
